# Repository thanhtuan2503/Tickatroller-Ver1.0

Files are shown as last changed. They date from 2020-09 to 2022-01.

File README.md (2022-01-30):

# Introduction to Tickatroller Ver1.0
- Tickatroller Ver1.0 is a control board for line follow car. Tickatroller have some functional blocks such as : encoder reader, esc control, serrvo control and 8 analog input. Besides that, it has jtag and icsp which makes debugging easier.
- Tickatroller use 12V power supply, and user must connect board with power supply before run or burn code.
- This project doesn't include souce code.

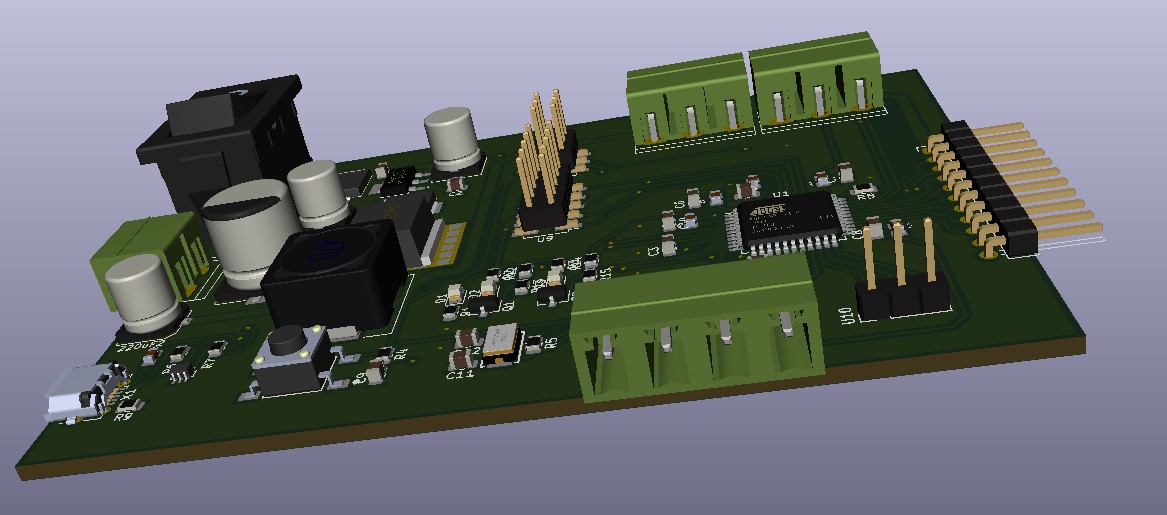
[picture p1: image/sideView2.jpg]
Side view of 3d render board with KiCad.

<p align="center">
    Side view of 3d render board with KiCad.
</p>

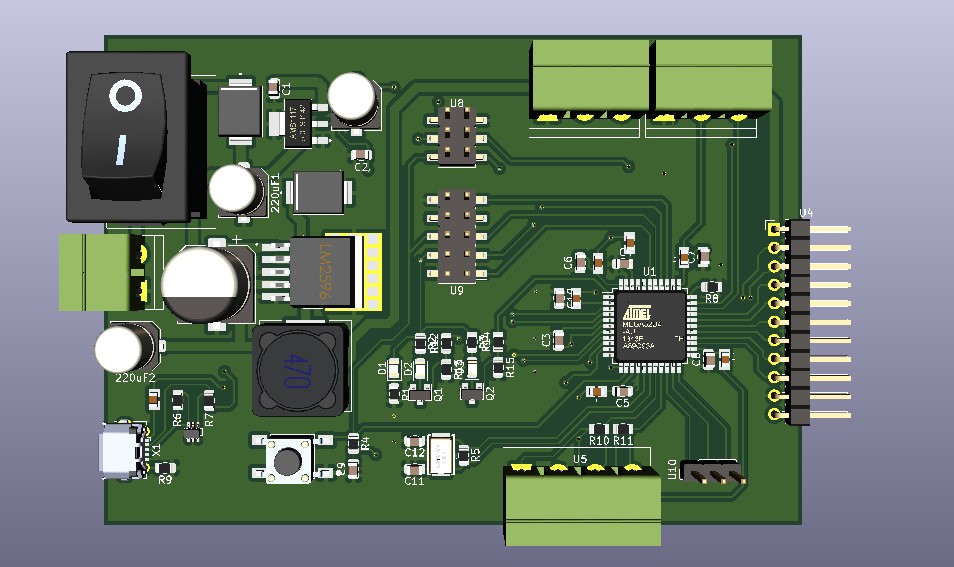
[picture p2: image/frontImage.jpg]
Top view of 3d render board with KiCad.

<p align="center">
    Top view of 3d render board with KiCad.
</p>

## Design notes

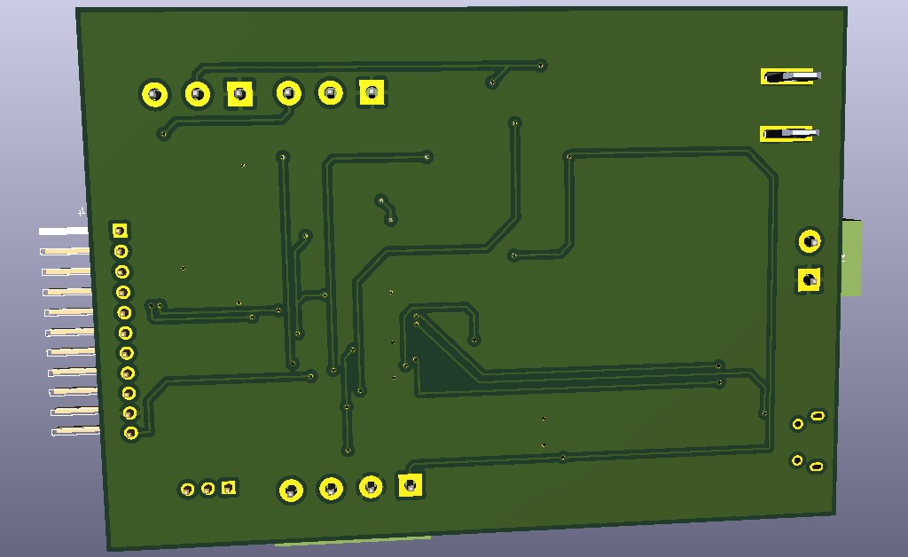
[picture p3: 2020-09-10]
image/bottomImage.jpg

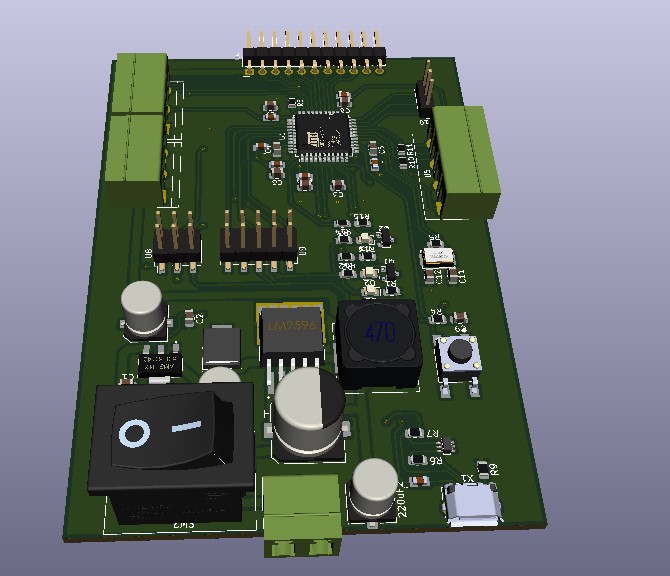
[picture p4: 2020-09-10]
image/sideView4.jpg

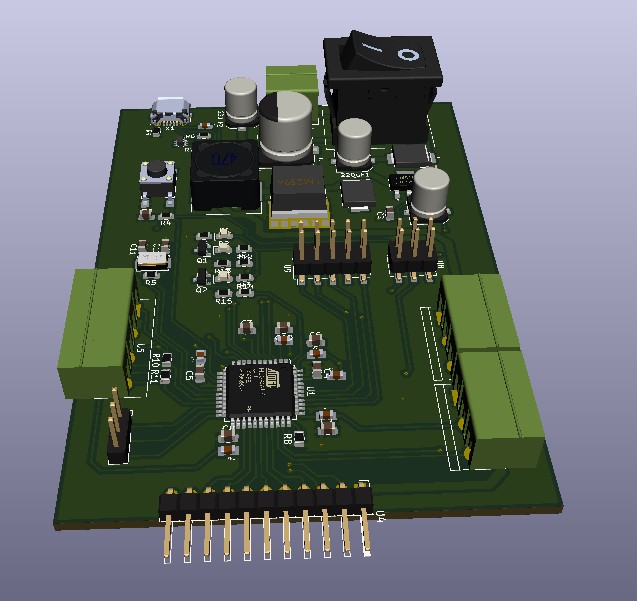
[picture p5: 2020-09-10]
image/sideView3.jpg

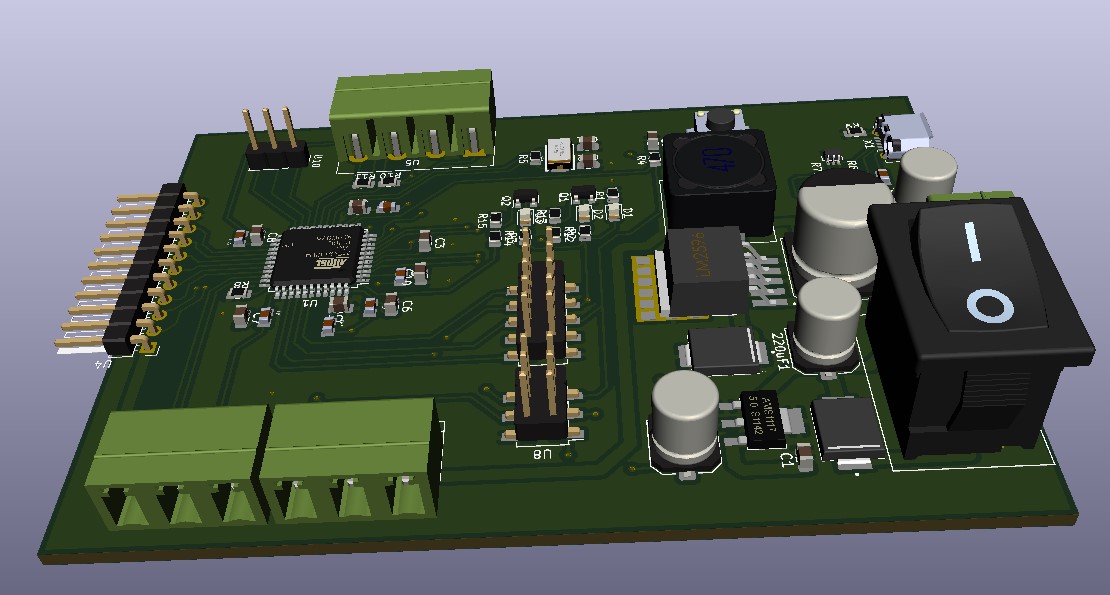
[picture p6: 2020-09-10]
image/sideView.jpg

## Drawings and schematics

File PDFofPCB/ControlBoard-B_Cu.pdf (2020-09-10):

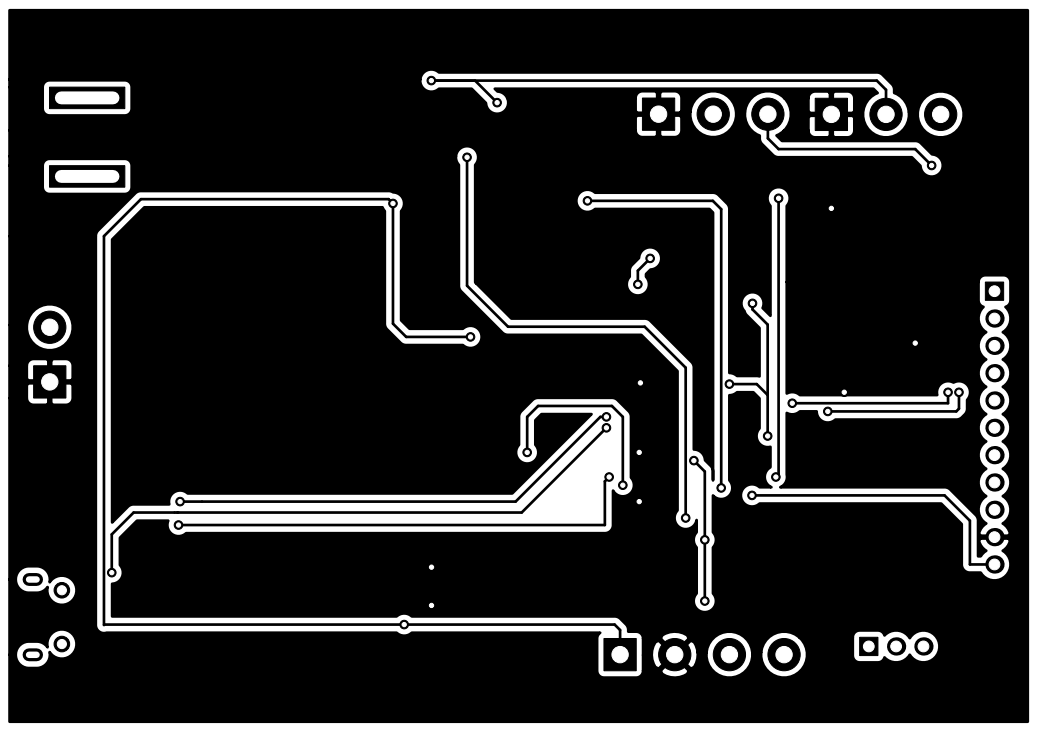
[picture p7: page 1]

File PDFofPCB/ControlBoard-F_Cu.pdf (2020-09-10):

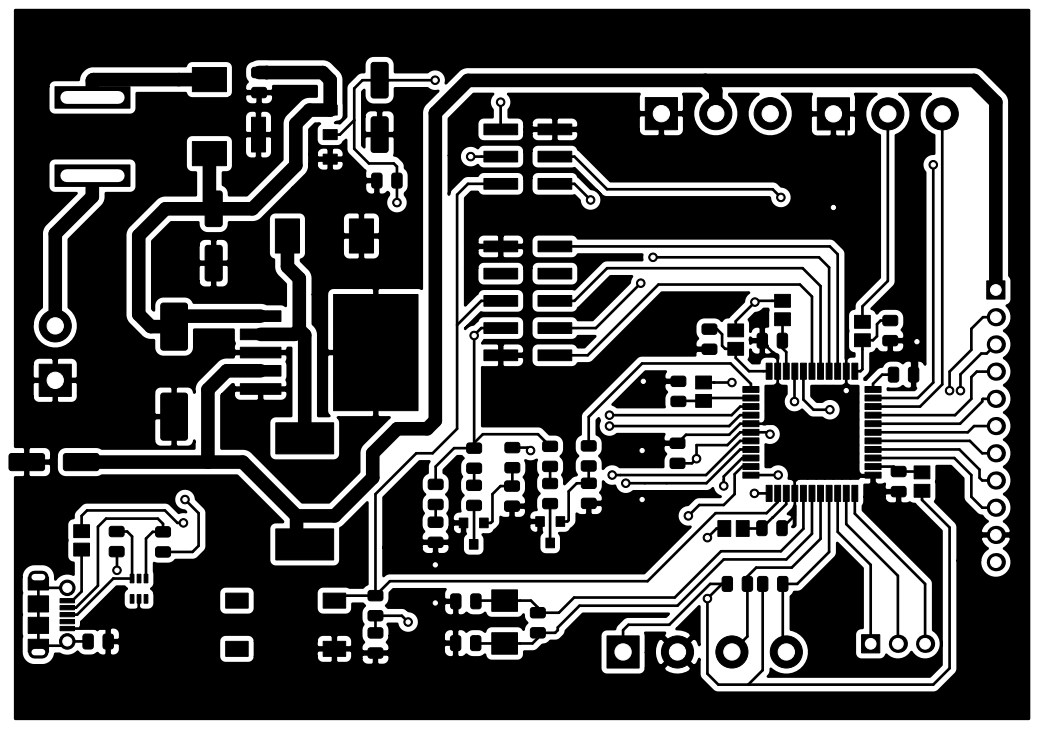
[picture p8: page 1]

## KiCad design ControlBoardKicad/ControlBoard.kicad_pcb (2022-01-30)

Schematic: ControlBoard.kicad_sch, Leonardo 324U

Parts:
1N5824: D_Schottky; SS34_SMC
33uH1: INDUCTOR; L_12x12mm_H8mm
220uF1: CP1; C_Elec_6.3x7.7
220uF2: CP4; C_Elec_6.3x7.7
220uF3: CP2; C_Elec_6.3x7.7
1000uF1: CP3; CP_Elec_10x10.5
C1, C2, C4, C5, C6, C7, C8, C9, C10: 0.1uF; C_0805_2012Metric
C3: 10uF; C_0805_2012Metric
C11, C12: 22pF; C_0805_2012Metric
D1: PWR; LED_0805_2012Metric
D2, D3: LED; LED_0805_2012Metric
D4: SS34; SS34_SMC
D5: SMF05C.TCT; SC70-6
F1: Polyfuse; FerriteBead
FB1, FB2, FB3, FB4, FB5, FB6: Ferrite; FerriteBead
J1: Conn_01x02_Female; TerminalBlock_bornier-2_P5.08mm
Q1, Q2: 2N7002; SOT-23
R1: 1K; R_0805_2012Metric
R2, R3: 470; R_0805_2012Metric
R4, R8, R10, R11: 10k; R_0805_2012Metric
R5: 1M; R_0805_2012Metric
R6, R7, R9: 22; R_0805_2012Metric
R12, R14: 10; R_0805_2012Metric
R13, R15: 10K; R_0805_2012Metric
SW1: ButtonFirst
SW2: SW_Push; SwitchPush
U1: ATMEGA32U4-AU; TQFP-44_10x10mm_Pitch0.8mm
U2: AMS1117
U3: LM2596S; LM2596S-5V
U4: LINE_BLOCK; PinHeader_1x11_P2.54mm_Horizontal
U5: ECD_BLOCK; TerminalBlock_bornier-4_P5.08mm
U6: ESC_BLOCK; TerminalBlock_bornier-3_P5.08mm
U7: SERVO_BLOCK; TerminalBlock_bornier-3_P5.08mm
U8: CODE_INPUT; PinHeader_2x03_P2.54mm_Vertical_SMD
U9: JTAG; PinHeader_2x05_P2.54mm_Vertical_SMD
U10: UART_BLOCK; PinHeader_1x03_P2.54mm_Vertical
X1: USB_OTG; USB_Micro-B_Molex-105017-0001
Y1: Crystal; 2-SMD-5X3

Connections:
+5V: 220uF3.1, C2.1, C3.1, C9.2, D1.2 (A), FB1.2, FB2.2, FB3.2, FB4.2, FB5.2, FB6.2, R2.1, R3.1, R4.2, R10.2, R11.2, U1.6 (UCAP), U2.2 (VOUT), U5.1 (ECD_VCC), U6.2 (VCC), U8.1 (VCC), U9.4 (VCC)
/2596_VCC: 220uF1.1, 1000uF1.1, C1.1, D4.2 (A), U2.3 (VIN), U3.1 (VIN)
/A1: U1.41 ((ADC0)PF0), U4.2 (ADC1)
/A2: U1.40 ((ADC1)PF1), U4.3 (ADC2)
/A3: U1.30 ((ADC13/OC1B/OC4B/PCINT13)PB6), U4.4 (ADC3)
/A4: U1.29 ((ADC12/OC1A/~OC4B/PCINT12)PB5), U4.5 (ADC4)
/A5: U1.28 ((ADC11/PCINT4)PB4), U4.6 (ADC5)
/A6: U1.27 ((T0/OC4D/ADC10)PD7), U4.7 (ADC6)
/A7: U1.26 ((T1/~OC4D/ADC9)PD6), U4.8 (ADC7)
/A8: U1.25 ((ICP2/ADC8)PD4), U4.9 (ADC8)
/CHA: R10.1, U1.18 ((OC0B/SCL/INT0)PD0), U5.3 (ECD_CHA)
/CHB: R11.1, U1.19 ((SDA/INT1)PD1), U5.4 (ECD_CHB)
/D0: U1.22 ((XCK1/~CTS)PD5), U10.3 (Digital)
/D+: R6.1, U1.4 (D+)
/D-: R7.1, U1.3 (D-)
/ESC_PPM: U1.31 ((OC3A/~OC4A)PC6), U6.3 (ESC_PPM)
/MISO: U1.11 ((PDO/MISO/PCINT3)PB3), U8.4 (MISO)
/MOSI: U1.10 ((PDI/MOSI/PCINT2)PB2), U8.3 (MOSI)
/PB0: R12.2, U1.8 ((SS/PCINT0)PB0)
/PE6: R14.2, U1.1 ((INT6/AIN0)PE6)
/PWM_LINE: U1.12 ((OC0A/OC1C/~RTS/PCINT7)PB7), U4.11 (PWM_LINE)
/RX: U1.20 ((RXD/INT2)PD2), U10.1 (RX)
/SCK: U1.9 ((SCLK/PCINT1)PB1), U8.6 (SCK)
/SERVO_PPM: U1.32 ((ICP3/CLK0/OC4A)PC7), U7.3 (SERVO_PPM)
/SER_VCC: 33uH1.2, 220uF2.1, U3.4 (FB), U4.1 (VCC_LINE), U7.2 (SERVO_VCC)
/TCK: U1.39 ((ADC4/TCK)PF4), U9.1 (TCK)
/TDI: U1.36 ((ADC7/TDI)PF7), U9.9 (TDI)
/TDO: U1.37 ((ADC6/TDO)PF6), U9.3 (TDO)
/TMS: U1.38 ((ADC5/TMS)PF5), U9.5 (TMS)
/TX: U1.21 ((TXD/INT3)PD3), U10.2 (TX)
/~RESET: R4.1, SW1.3, U1.13 (~RESET), U8.5 (RST), U9.6 (RESET)
GND: 1N5824.2 (A), 220uF1.2, 220uF2.2, 220uF3.2, 1000uF1.2, C1.2, C2.2, C3.2, C4.2, C5.1, C6.1, C7.1, C8.1, C9.1, C10.1, C11.2, C12.2, D5.2 (GND), J1.1, Q1.2 (S), Q2.2 (S), R1.2, R8.1, R9.1, R13.2, R15.2, SW1.1, U1.5 (UGND), U1.15 (GND), U1.23 (GND), U1.35 (GND), U1.43 (GND), U2.1 (GND), U2.4 (SHIELD), U3.3 (GND), U3.5 (ON/OFF), U3.6 (SHIELD), U4.10 (GND_LINE), U5.2 (ECD_GND), U6.1 (GND), U7.1 (SERVO_GND), U8.2 (GND), U9.2 (GND), U9.10 (GND), X1.5 (GND)
unnamed: 1N5824.1 (K), 33uH1.1, U3.2 (VOUT)
unnamed: C4.1, FB1.1, U1.42 (AREF)
unnamed: C5.2, FB3.1, U1.14 (VCC)
unnamed: C6.2, FB2.1, U1.44 (AVCC)
unnamed: C7.2, FB4.1, U1.34 (VCC)
unnamed: C8.2, FB5.1, U1.24 (AVCC)
unnamed: C10.2, FB6.1, U1.2 (UVCC)
unnamed: C11.1, R5.2, U1.17 (XTAL1), Y1.2
unnamed: C12.1, R5.1, U1.16 (XTAL2), Y1.1
unnamed: D1.1 (K), R1.1
unnamed: D2.1 (K), Q1.3 (D)
unnamed: D2.2 (A), R2.2
unnamed: D3.1 (K), Q2.3 (D)
unnamed: D3.2 (A), R3.2
unnamed: D4.1 (K), SW2.2
unnamed: D5.4 (IO3), R7.2, X1.2 (D-)
unnamed: D5.6 (IO5), R6.2, X1.3 (D+)
unnamed: F1.2, X1.1 (VBUS)
unnamed: J1.2, SW2.1
unnamed: Q1.1 (G), R12.1, R13.1
unnamed: Q2.1 (G), R14.1, R15.1
unnamed: R8.2, U1.33 ((~HWB)PE2)
unnamed: R9.2, X1.6 (Shield)
VBUS: F1.1, U1.7 (VBUS)

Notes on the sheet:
OUTPUT BLOCK
SOURCE BLOCK
DEBUG AND INPUT BLOCK

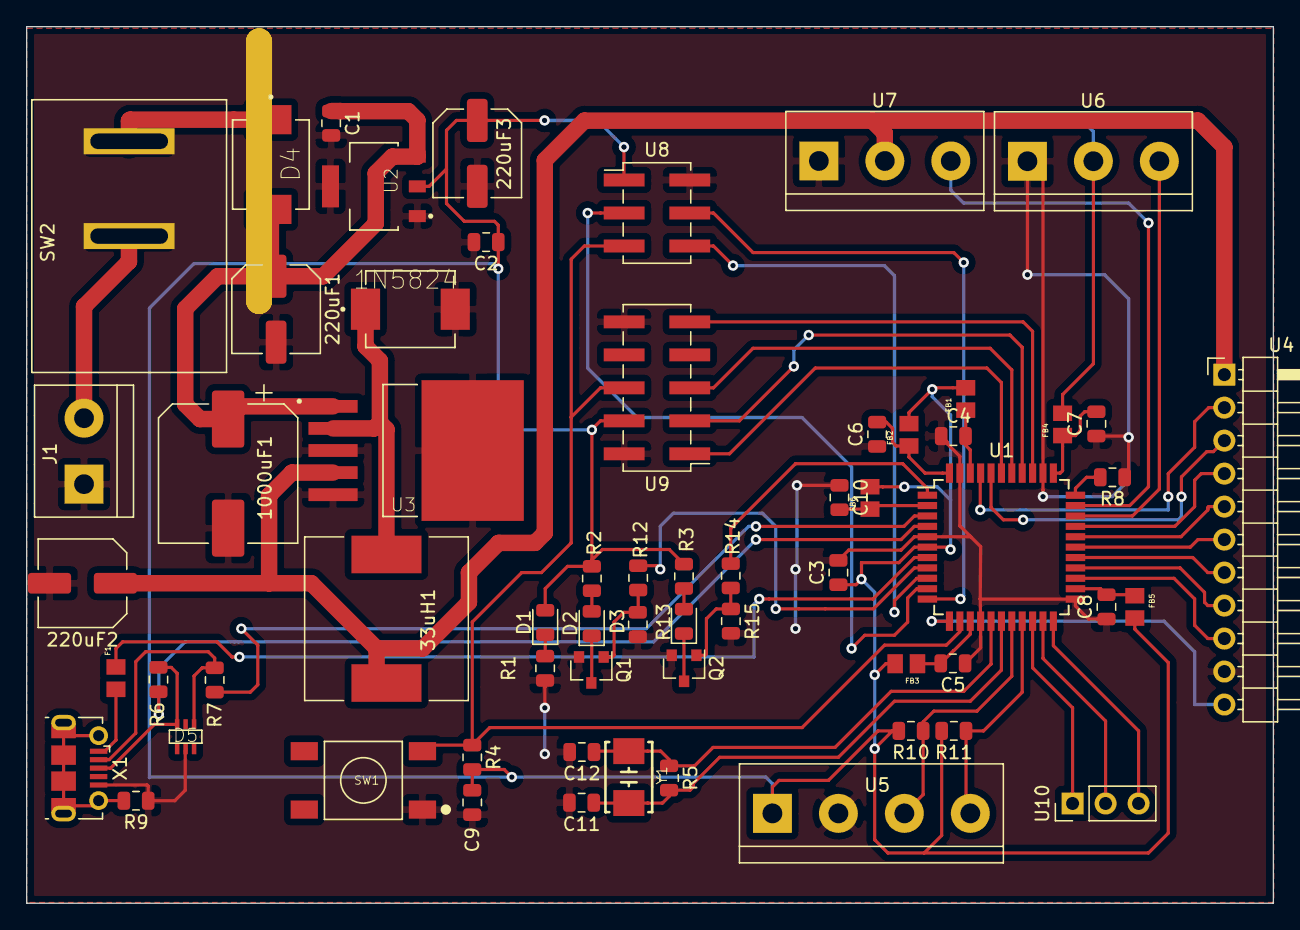
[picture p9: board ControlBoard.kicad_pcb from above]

Board: 2 copper layers, 96.0 x 67.5 mm, 62 parts (0 on the bottom side), 56 nets.

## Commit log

2020-09-10 First Layout
    [ControlBoard.csv, ControlBoard.kicad_pcb, ControlBoard.sch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]
2020-09-10 Finish Readme file
    [ControlBoard.kicad_pcb]
2020-09-10 plot 2 face of pcb board
2022-01-30 Change work folder
    [ControlBoard.csv, ControlBoard.kicad_pcb, ControlBoard.kicad_sch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]
